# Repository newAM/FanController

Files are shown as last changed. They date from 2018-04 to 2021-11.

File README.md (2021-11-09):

## IR Fan Controller

### What is it?
This project is an Ethernet connected IR remote control for a the Seville classics ultra slimline tower fan, but it can be easily adapted to control other IR devices.  

### Why?
To connect my fan to Home Assistant so that it can turn on automatically when it gets hot, and turn off automatically when I leave home.

#### Why PoE?
Wireless home automation devices often make sense only when they are battery powered, if a power cable needs to be run it can carry data too.  Designing a low power wireless device is far more complicated than designing a wired device and running an Ethernet cable.

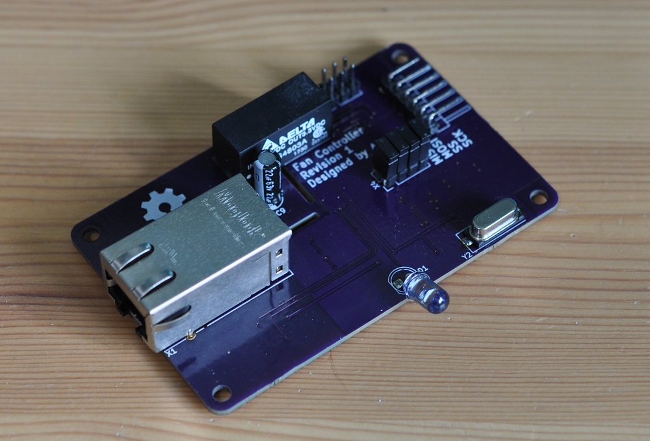
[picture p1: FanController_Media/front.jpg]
front


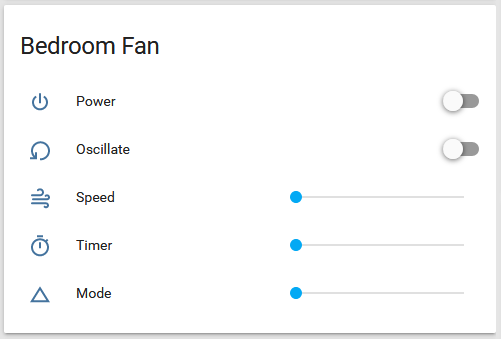
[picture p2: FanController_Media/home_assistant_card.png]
home_assistant_card


## Overview
Home Assistant → MQTT Broker → W5100 (Ethernet) → ATMega328P (MCU) → IR LED

The controller takes the states of the power, oscillation, mode, timer, and speed from Home Assistant.  These values are used to build the IR code then transmit it through the IR LED.

## Project Contents
* FanController_ArduinoCode - firmware for the ATMega328P
* FanController_Guide - reverse engineering guide for IR codes
* FanController_HomeAssistant - example Home Assistant configuration
* FanController_KiCAD - schematic and PCB
* FanController_Media - photos

## Software Used
* [KiCad](http://kicad.org/)
* [Arduino IDE](https://www.arduino.cc/en/Main/Software)
* [OpenSCAD](http://www.openscad.org/)
* [Libre Office](https://www.libreoffice.org/)
* [Home Assistant](https://www.home-assistant.io/)

### Arduino Libraries used
* [Arduino MQTT Client](https://github.com/knolleary/pubsubclient)

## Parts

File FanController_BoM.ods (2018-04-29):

Reference | Value | Tolerance | Rating | Package | Digikey P/N | Quantity
Integrated Circuits
U1 | ATMEGA328P-AU |  |  | 32-TQFP | ATMEGA328P-AU-ND | 1
U2 | NCP1090 |  |  | 8-SOIC | NCP1090DGOS-ND | 1
U3 | PG02S4803A |  |  | 8-SIP | 941-1185-ND | 1
U4 | W5100 |  |  | 80-LQFP (10) | 1278-1002-ND | 1
Resistors | Ohms |  | Watts
R1-R4 | 49.9 | 1% | 0.25 | 0805 | RNCP0805FTD49R9CT-ND | 4
R5 | 150 | 1% | 0.1 | 0603 | 311-150HRCT-ND | 1
R6 | 10 | 1% | 0.25 | 0805 | RNCP0805FTD10R0CT-ND | 1
R7, R13-R15 | 12k | 1% | 0.1 | 0603 | 311-12.0KHRCT-ND | 4
R8 | 24.9k | 1% | 0.1 | 0603 | 311-24.9KHRCT-ND | 1
R9 | 178k | 1% | 0.1 | 0603 | 311-178KHRCT-ND | 1
R10 | 4420 | 1% | 0.1 | 0603 | 311-4.42KHRCT-ND | 1
R11 | 300 | 1% | 0.1 | 0603 | 311-300HRCT-ND | 1
R12 | 1M | 5% | 0.1 | 0603 | 311-1.0MGRCT-ND | 1
Capacitors | Farads |  | Volts
C1-C6, C10-C12, C14, C16, C17 | 100n | 10% | 16 | 0603 | 1276-1005-1-ND | 10
C7 | 100n | 10% | 100 | 0805 | 1276-6840-1-ND | 1
C8 | 22u | 20% | 63 | 5mm | 493-12798-1-ND | 1
C9 | 10u | 10% | 10 | 0805 | 1276-6456-1-ND | 1
C13, C15 | 18p | 5% | 50 | 0603 | 1276-1089-1-ND | 2
Inductors | Henries |  | Amperes
L1 | 1u | 20% | 600m | 0603 | 445-3163-1-ND | 1
Oscillators | Hertz
Y1 | 8MHz |  |  |  | 490-1195-1-ND | 1
Y2 | 25M | 30ppm |  | HC49 | 535-10235-1-ND | 1
Connectors
X1 | 0813-1X1T-57-F |  |  |  | 507-1421-ND | 1
X2 | ICSP |  |  | 2*3 2.54mm | 952-1779-ND | 1
X3 | SPI Disconnect |  |  | 2*4 2.54mm | 952-2123-ND | 1
X4 | Serial Interface |  |  | 1*5 2.54mm RA | N/A | 1
Diodes
D1 | IR |  |  | 5mm |  | 1
D2, D3 | MDB6S |  |  | 4-MicroDIP | MDB6SFSCT-ND | 2
D4 | SMAJ58A |  |  | SMA | SMAJ58A-E3/61GICT-ND | 1
Transistors
Q1 | MMBT3904 |  |  | SOT-23-3 | MMBT3904LT1GOSCT-ND | 1
Other
Jumpers |  |  |  |  | S9000-ND | 4
PCB |  |  |  |  | N/A | 1

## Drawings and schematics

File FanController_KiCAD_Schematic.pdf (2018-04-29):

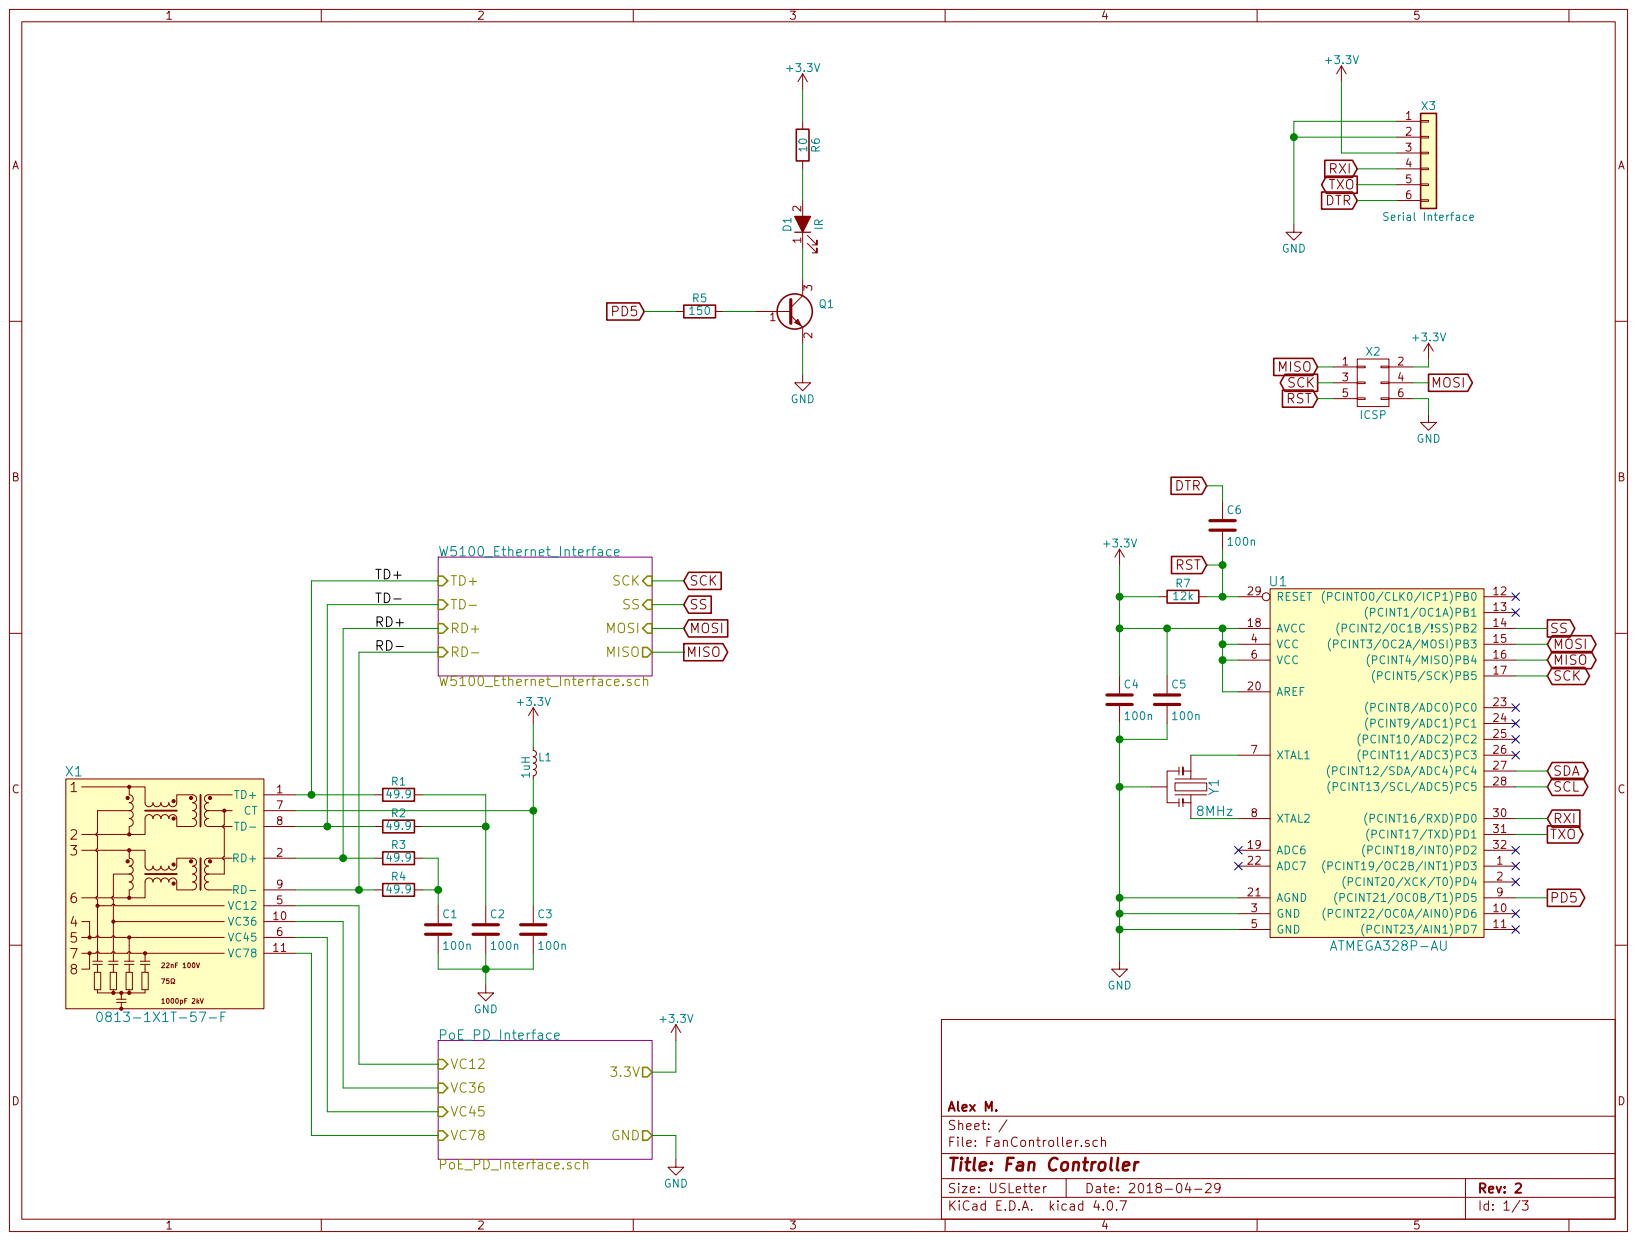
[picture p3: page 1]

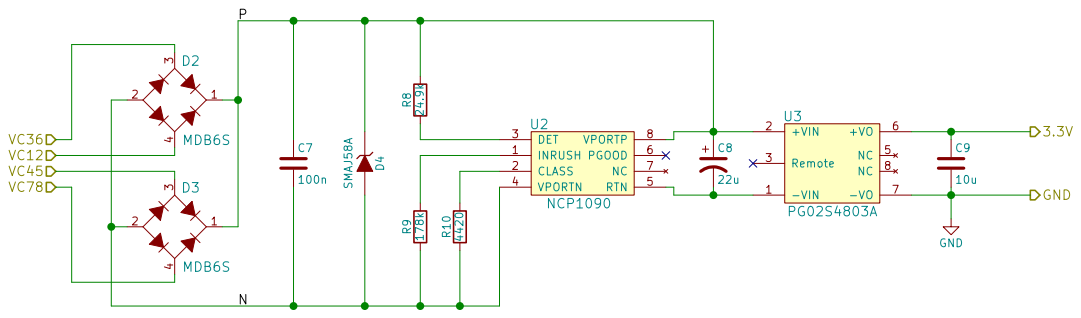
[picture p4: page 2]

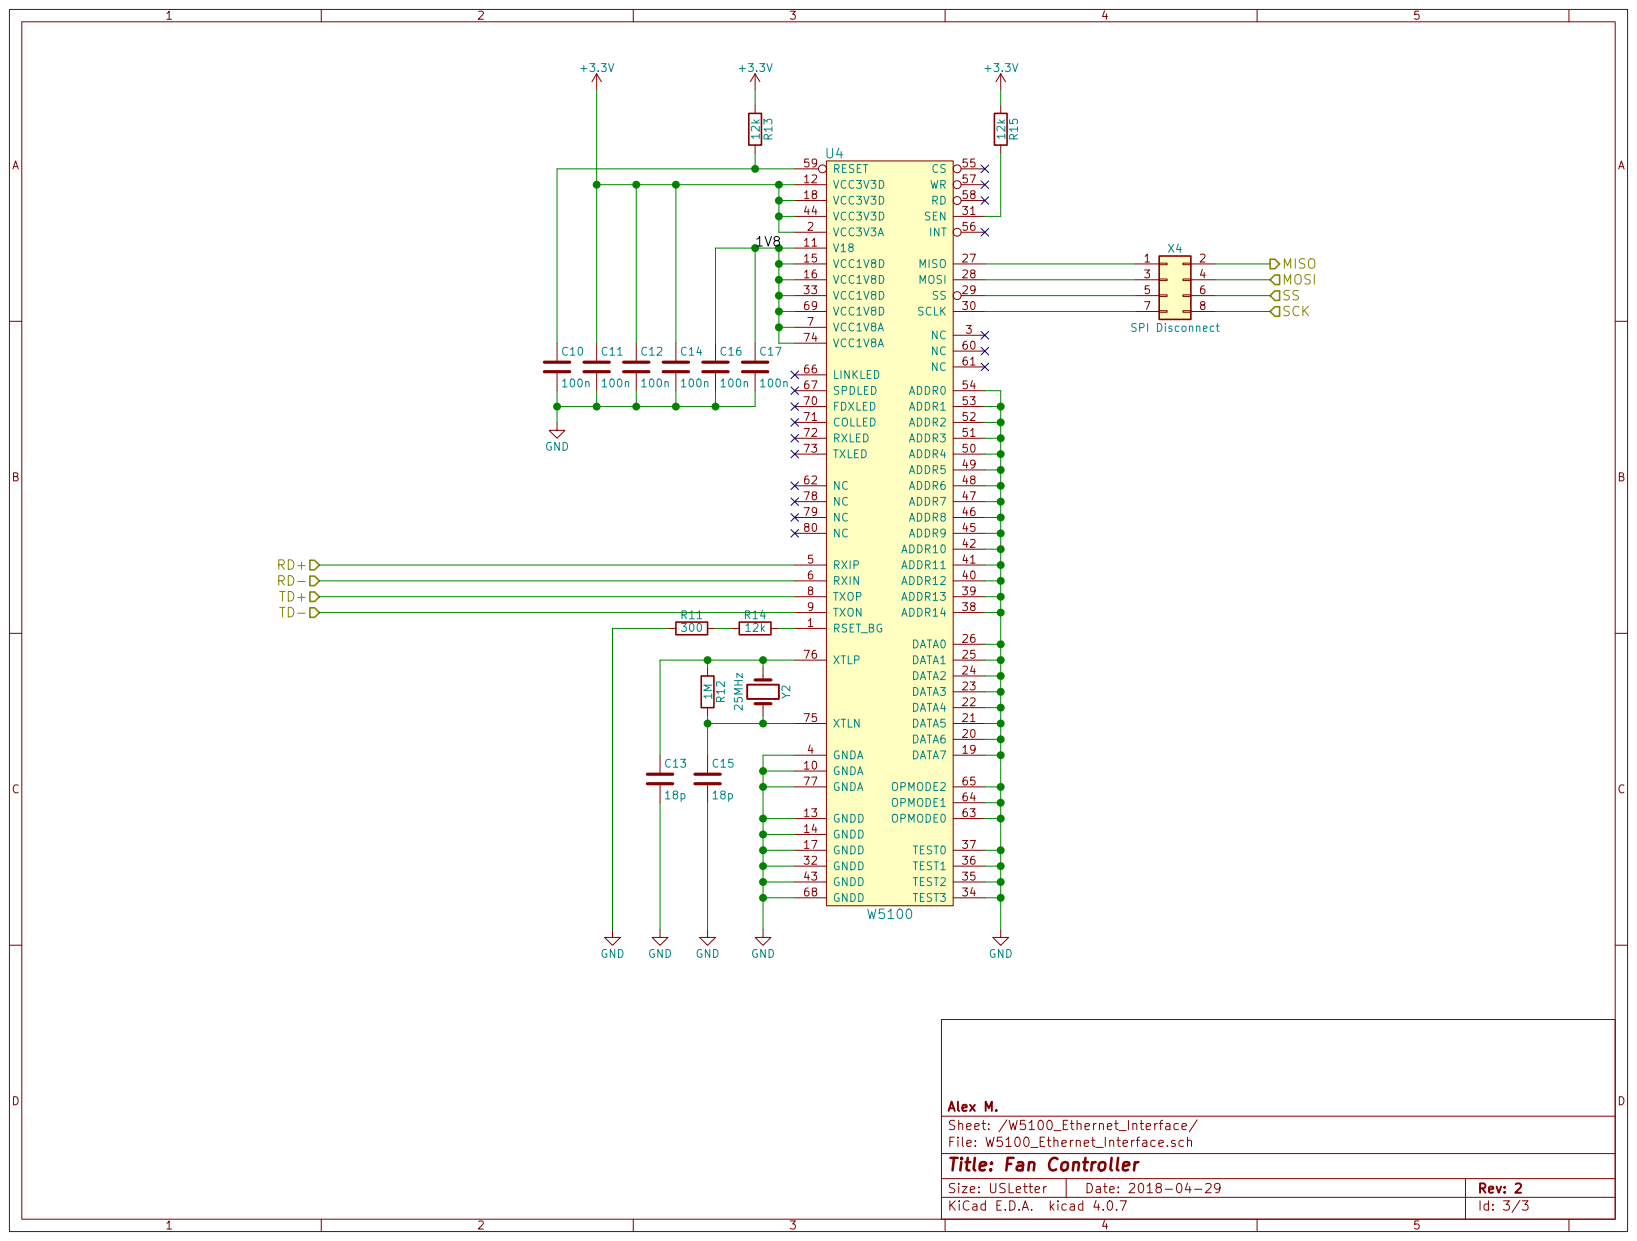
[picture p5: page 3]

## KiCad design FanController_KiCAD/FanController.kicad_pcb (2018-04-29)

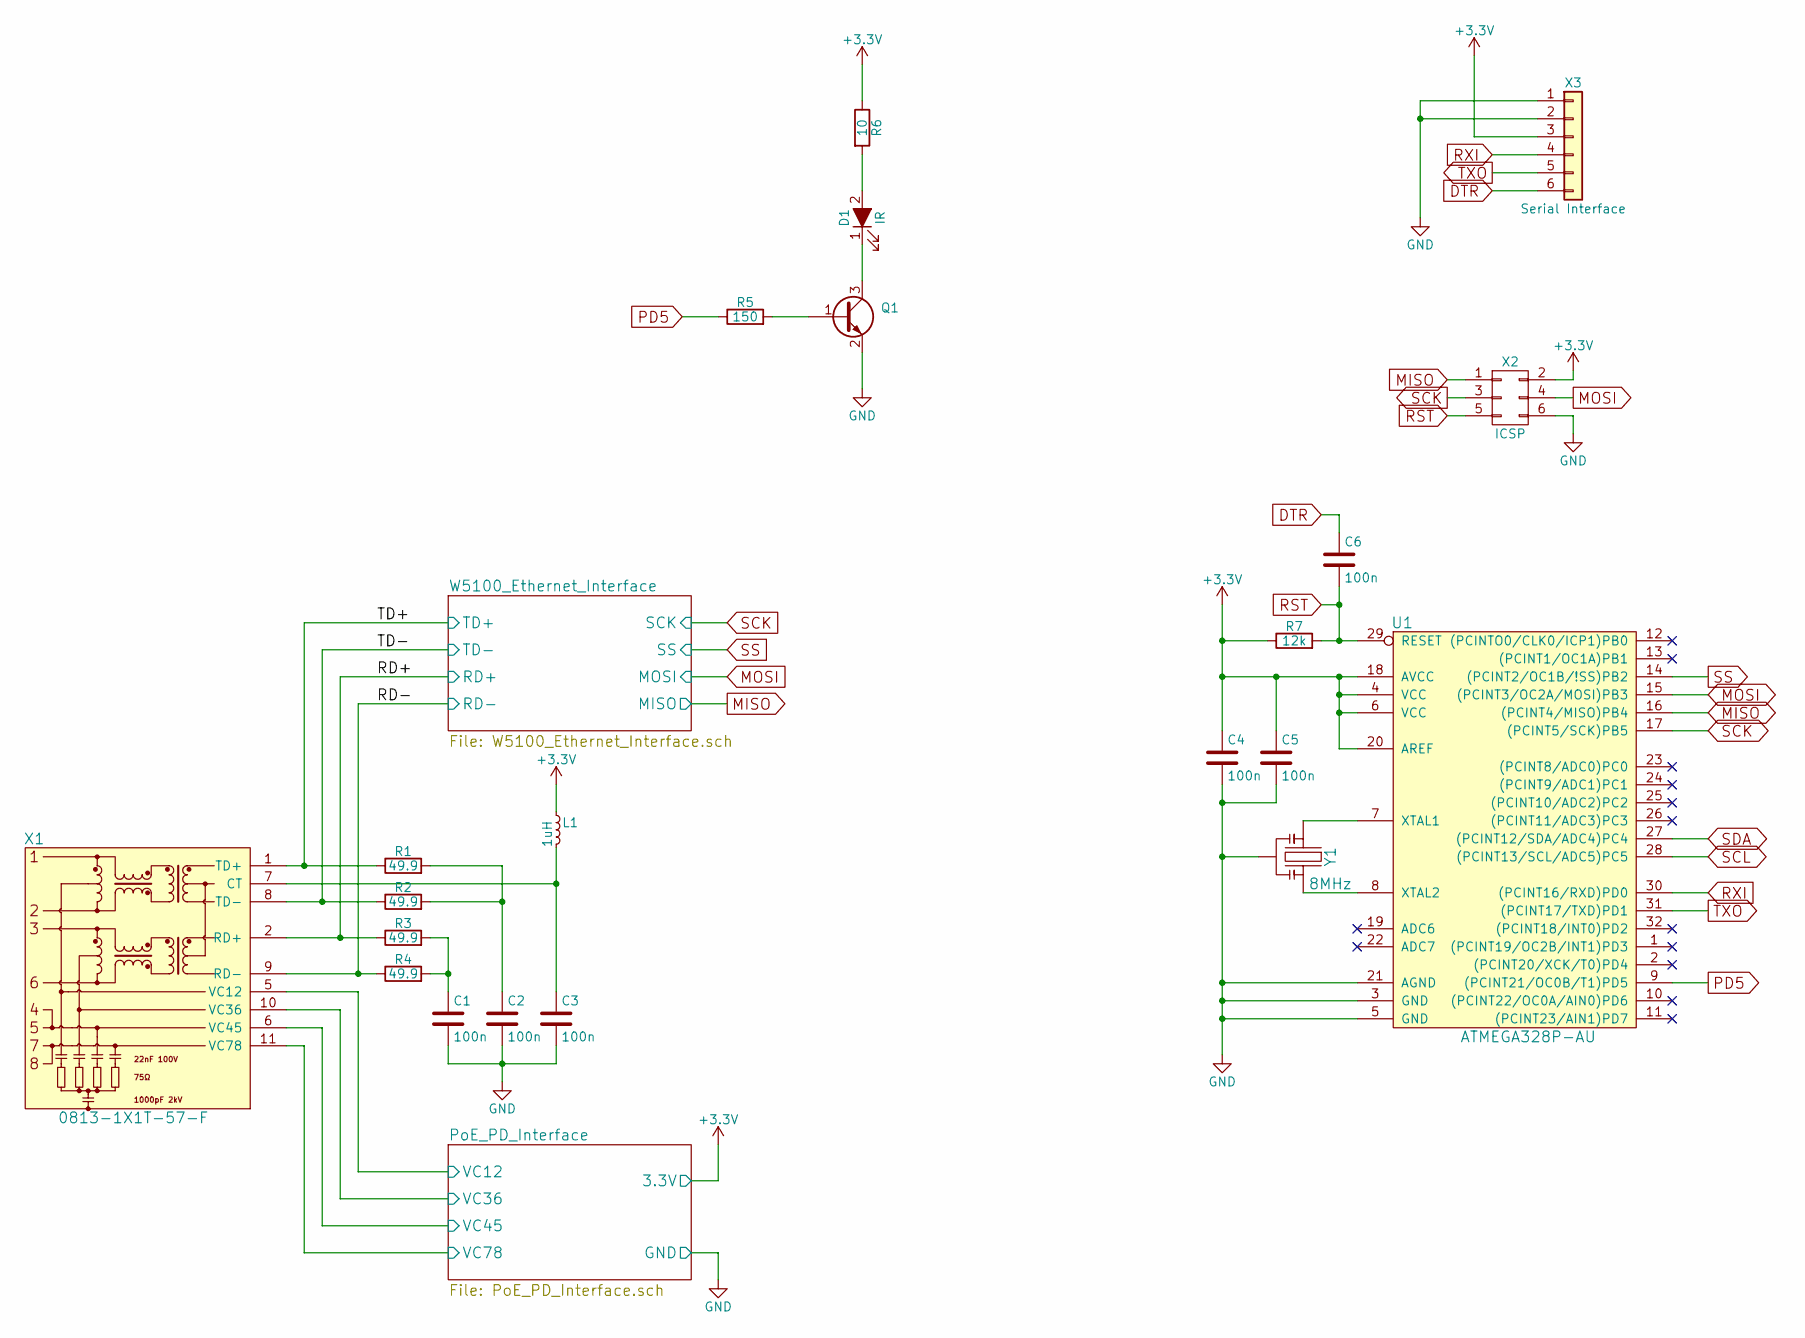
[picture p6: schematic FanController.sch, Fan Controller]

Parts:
C1, C2, C3, C4, C5, C6: 100n; C_0603; DigiKey Part Number 1276-1005-1-ND
D1: IR; LED_D5.0mm
L1: 1uH; C_0603; DigiKey Part Number 445-3163-1-ND
Q1: Q_NPN_BEC; SOT-23; DigiKey Part Number MMBT3904LT1GOSCT-ND
R1, R2, R3, R4: 49.9; R_0805; DigiKey Part Number RNCP0805FTD49R9CT-ND
R5: 150; R_0603; Tolerance 1%; DigiKey Part Number 311-150HRCT-ND
R6: 10; R_0805; DigiKey Part Number RNCP0805FTD10R0CT-ND
R7: 12k; R_0603; Tolerance 1%; DigiKey Part Number 311-12.0KHRCT-ND
U1: ATMEGA328P-AU; TQFP-32_7x7mm_Pitch0.8mm; DigiKey Part Number ATMEGA328P-AU-ND
X1: 0813-1X1T-57-F; 0813-1X1T-57-F_RJ45-Jack; DigiKey Part Number 507-1421-ND
X2: ICSP; Pin_Header_Straight_2x03_Pitch2.54mm
X3: Serial Interface; Pin_Header_Angled_1x06_Pitch2.54mm
Y1: 8MHz; CERALOCK_CSTCE_Resonator; DigiKey Part Number 490-1195-1-ND

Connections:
+3V3: C4.1, C5.1, L1.1, R6.1, R7.1, U1.4 (VCC), U1.6 (VCC), U1.18 (AVCC), U1.20 (AREF), X2.2, X3.3; also elsewhere on the board
/PoE_PD_Interface/VC12: X1.5 (VC12); also elsewhere on the board
/PoE_PD_Interface/VC36: X1.10 (VC36); also elsewhere on the board
/PoE_PD_Interface/VC45: X1.6 (VC45); also elsewhere on the board
/PoE_PD_Interface/VC78: X1.11 (VC78); also elsewhere on the board
/RD+: R3.1, X1.2 (RD+); also elsewhere on the board
/RD-: R4.1, X1.9 (RD-); also elsewhere on the board
/TD+: R1.1, X1.1 (TD+); also elsewhere on the board
/TD-: R2.1, X1.8 (TD-); also elsewhere on the board
DTR: C6.1, X3.6
GND: C1.2, C2.2, C3.2, C4.2, C5.2, Q1.2 (E), U1.3 (GND), U1.5 (GND), U1.21 (AGND), X2.6, X3.1, X3.2, Y1.2; also elsewhere on the board
MISO: U1.16 ((PCINT4/MISO)PB4), X2.1; also elsewhere on the board
MOSI: U1.15 ((PCINT3/OC2A/MOSI)PB3), X2.4; also elsewhere on the board
unnamed: C1.1, R3.2, R4.2
unnamed: C2.1, R1.2, R2.2
unnamed: C3.1, L1.2, X1.7 (CT)
unnamed: D1.1 (K), Q1.3 (C)
unnamed: D1.2 (A), R6.2
unnamed: Q1.1 (B), R5.2
unnamed: U1.7 (XTAL1), Y1.1
unnamed: U1.8 (XTAL2), Y1.3
PD5: R5.1, U1.9 ((PCINT21/OC0B/T1)PD5)
RST: C6.2, R7.2, U1.29 (RESET), X2.5
RXI: U1.30 ((PCINT16/RXD)PD0), X3.4
SCK: U1.17 ((PCINT5/SCK)PB5), X2.3; also elsewhere on the board
SS: U1.14 ((PCINT2/OC1B/!SS)PB2); also elsewhere on the board
TXO: U1.31 ((PCINT17/TXD)PD1), X3.5

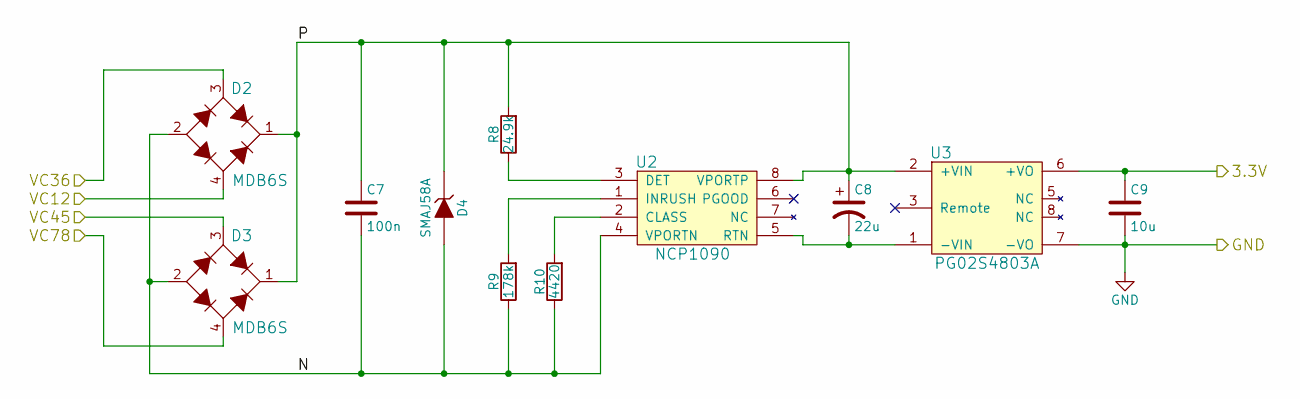
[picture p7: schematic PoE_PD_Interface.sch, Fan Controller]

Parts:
C7: 100n; C_0805; DigiKey Part Number 1276-6840-1-ND
C8: 22u; CP_Radial_D5.0mm_P2.00mm; DigiKey Part Number 493-12798-1-ND
C9: 10u; C_0805; DigiKey Part Number 1276-6456-1-ND
D2, D3: MDB6S; Micro-DIP-4; DigiKey Part Number MDB6SFSCT-ND
D4: SMAJ58A; D_SMA; DigiKey Part Number SMAJ58A-E3/61GICT-ND
R8: 24.9k; R_0603; DigiKey Part Number 311-24.9KHRCT-ND
R9: 178k; R_0603; DigiKey Part Number 311-178KHRCT-ND
R10: 4420; R_0603; DigiKey Part Number 311-4.42KHRCT-ND
U2: NCP1090; SOIC-8_3.9x4.9mm_Pitch1.27mm; DigiKey Part Number NCP1090DGOS-ND
U3: PG02S4803A; PG02S; DigiKey Part Number 941-1185-ND

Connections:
+3V3: C9.1, U3.6 (+VO); also elsewhere on the board
/PoE_PD_Interface/N: C7.2, D2.2 (-), D3.2 (-), D4.2 (A), R9.1, R10.1, U2.4 (VPORTN)
/PoE_PD_Interface/P: C7.1, C8.1, D2.1 (+), D3.1 (+), D4.1 (K), R8.2, U2.8 (VPORTP), U3.2 (+VIN)
/PoE_PD_Interface/VC12: D2.4 (AC2); also elsewhere on the board
/PoE_PD_Interface/VC36: D2.3 (AC1); also elsewhere on the board
/PoE_PD_Interface/VC45: D3.3 (AC1); also elsewhere on the board
/PoE_PD_Interface/VC78: D3.4 (AC2); also elsewhere on the board
GND: C9.2, U3.7 (-VO); also elsewhere on the board
unnamed: C8.2, U2.5 (RTN), U3.1 (-VIN)
unnamed: R8.1, U2.3 (DET)
unnamed: R9.2, U2.1 (INRUSH)
unnamed: R10.2, U2.2 (CLASS)

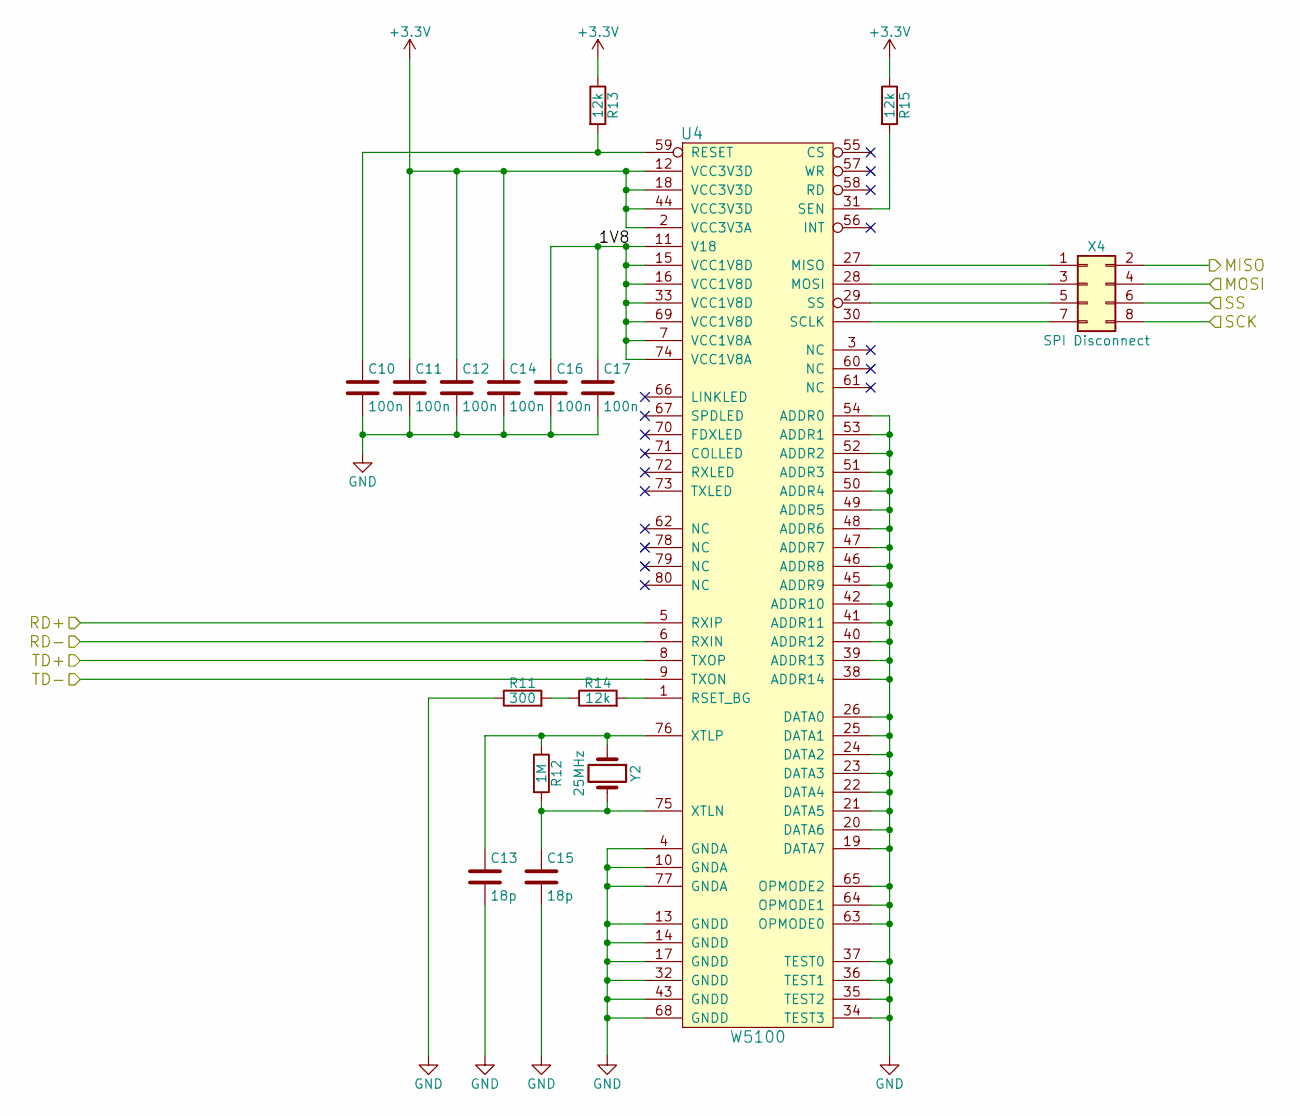
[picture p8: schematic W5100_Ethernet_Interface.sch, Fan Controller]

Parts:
C10, C11, C12, C14, C16, C17: 100n; C_0603; DigiKey Part Number 1276-1005-1-ND
C13, C15: 18p; C_0603; DigiKey Part Number 1276-1089-1-ND
R11: 300; R_0603; Tolerance 1%; DigiKey Part Number 311-300HRCT-ND
R12: 1M; R_0603; Tolerance 1%; DigiKey Part Number 311-1.00MHRCT-ND
R13, R14, R15: 12k; R_0603; Tolerance 1%; DigiKey Part Number 311-12.0KHRCT-ND
U4: W5100; LQFP-80_10x10mm_Pitch0.4mm; DigiKey Part Number 1278-1002-ND
X4: SPI Disconnect; Pin_Header_Straight_2x04_Pitch2.54mm
Y2: 25MHz; Crystal_SMD_HC49-SD; DigiKey Part Number 535-10235-1-ND

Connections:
+3V3: C11.1, C12.1, C14.1, R13.1, R15.1, U4.2 (VCC3V3A), U4.12 (VCC3V3D), U4.18 (VCC3V3D), U4.44 (VCC3V3D); also elsewhere on the board
/RD+: U4.5 (RXIP); also elsewhere on the board
/RD-: U4.6 (RXIN); also elsewhere on the board
/TD+: U4.8 (TXOP); also elsewhere on the board
/TD-: U4.9 (TXON); also elsewhere on the board
/W5100_Ethernet_Interface/1V8: C16.1, C17.1, U4.7 (VCC1V8A), U4.11 (V18), U4.15 (VCC1V8D), U4.16 (VCC1V8D), U4.33 (VCC1V8D), U4.69 (VCC1V8D), U4.74 (VCC1V8A)
GND: C10.2, C11.2, C12.2, C13.2, C14.2, C15.2, C16.2, C17.2, R11.1, U4.4 (GNDA), U4.10 (GNDA), U4.13 (GNDD), U4.14 (GNDD), U4.17 (GNDD), U4.19 (DATA7), U4.20 (DATA6), U4.21 (DATA5), U4.22 (DATA4), U4.23 (DATA3), U4.24 (DATA2), U4.25 (DATA1), U4.26 (DATA0), U4.32 (GNDD), U4.34 (TEST3), U4.35 (TEST2), U4.36 (TEST1), U4.37 (TEST0), U4.38 (ADDR14), U4.39 (ADDR13), U4.40 (ADDR12), U4.41 (ADDR11), U4.42 (ADDR10), U4.43 (GNDD), U4.45 (ADDR9), U4.46 (ADDR8), U4.47 (ADDR7), U4.48 (ADDR6), U4.49 (ADDR5), U4.50 (ADDR4), U4.51 (ADDR3), U4.52 (ADDR2), U4.53 (ADDR1), U4.54 (ADDR0), U4.63 (OPMODE0), U4.64 (OPMODE1), U4.65 (OPMODE2), U4.68 (GNDD), U4.77 (GNDA); also elsewhere on the board
MISO: X4.2; also elsewhere on the board
MOSI: X4.4; also elsewhere on the board
unnamed: C10.1, R13.2, U4.59 (RESET)
unnamed: C13.1, R12.1, U4.76 (XTLP), Y2.1
unnamed: C15.1, R12.2, U4.75 (XTLN), Y2.2
unnamed: R11.2, R14.1
unnamed: R14.2, U4.1 (RSET_BG)
unnamed: R15.2, U4.31 (SEN)
unnamed: U4.27 (MISO), X4.1
unnamed: U4.28 (MOSI), X4.3
unnamed: U4.29 (SS), X4.5
unnamed: U4.30 (SCLK), X4.7
SCK: X4.8; also elsewhere on the board
SS: X4.6; also elsewhere on the board

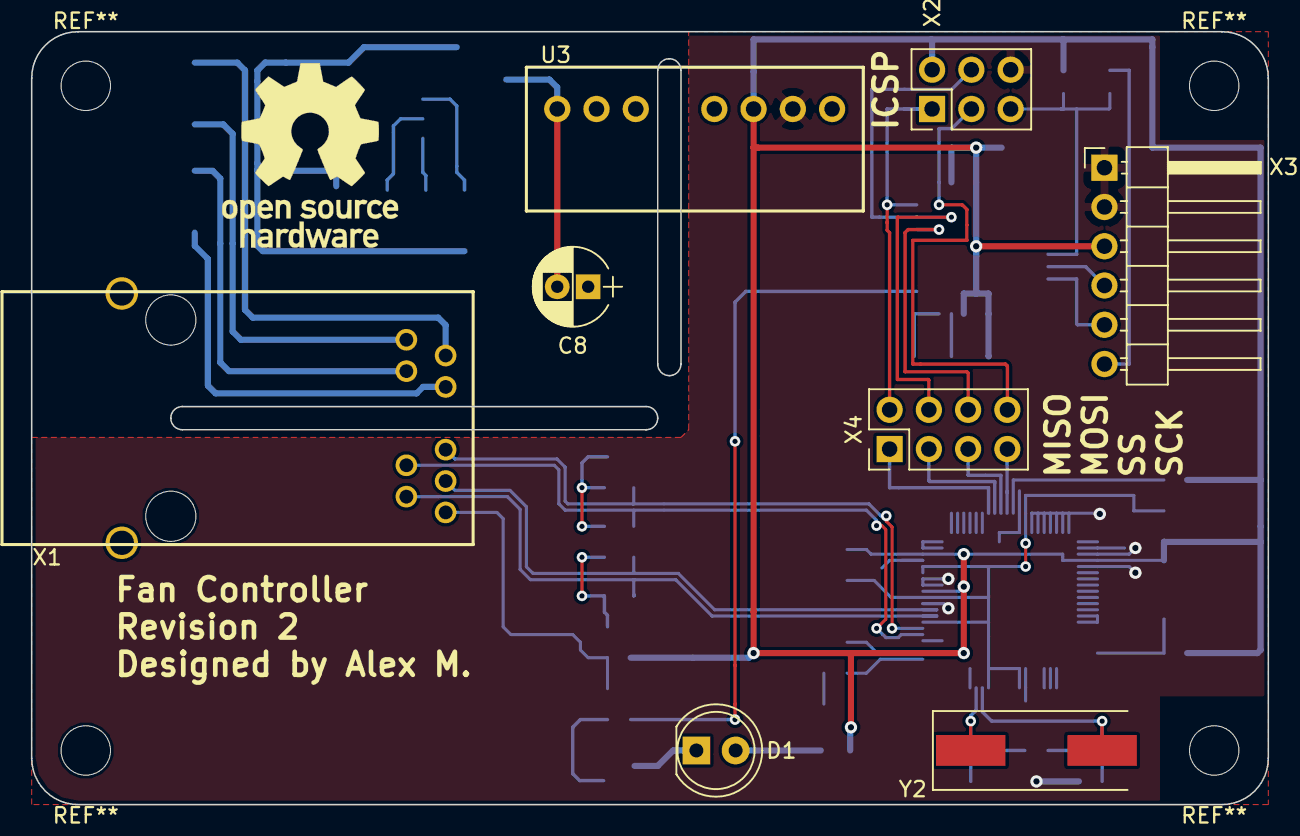
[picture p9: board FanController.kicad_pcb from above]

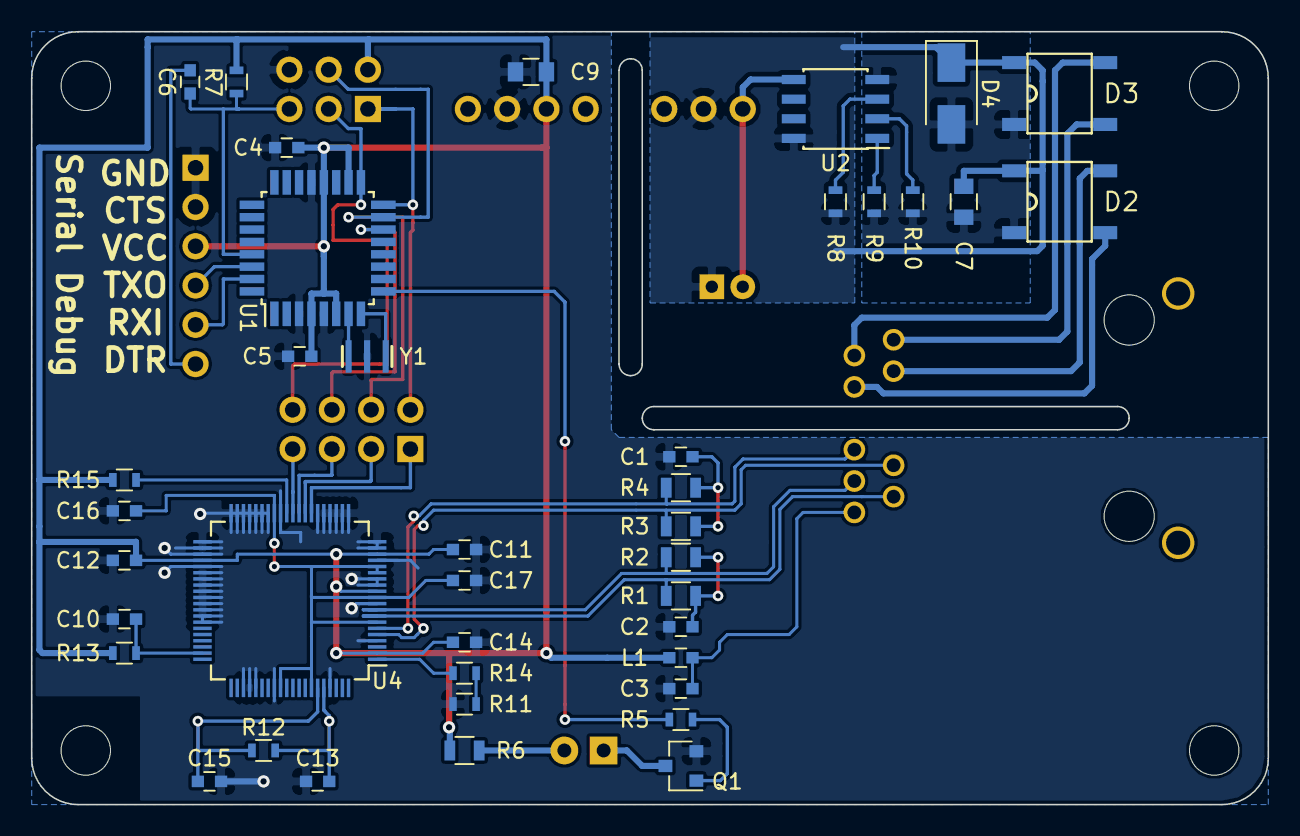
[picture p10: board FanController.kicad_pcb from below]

Board: 2 copper layers, 80.0 x 50.0 mm, 48 parts (40 on the bottom side), 44 nets.

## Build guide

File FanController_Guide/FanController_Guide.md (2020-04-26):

## Contents
- [Introduction](#introduction)
- [Background](#background)
    - [IR Data Formats](#ir-data-formats)
    - [Types of IR Remotes](#types-of-ir-remotes)
        - [Types of IR Remotes](#single-command-remotes)
        - [All at Once Remotes](#all-at-once-remotes)
- [Reading IR Commands](#reading-ir-commands)
- [Determining the Protocol](#determining-the-protocol)

## Introduction

This is not a full guide to reverse engineering IR remote controls.  This guide outlines the process I went through to create this controller, and provides some guidance on adapting it for your application.

## Background

This guide will not go into the very basics behind IR communication, check out [this guide](http://www.learn.sparkfun.com/tutorials/ir-communication) by SparkFun to get the basics of IR communication.

### IR Data Formats

There's a few different types of data formats for IR remote controls, and a few common carrier frequencies. The most common carrier frequency for IR remotes is 38kHz, it is usually a good idea to start there.

[This document](http://www.vishay.com/docs/80071/dataform.pdf) by VISHAY covers the data formats and carrier frequencies that you are likely to come across when reverse engineering an IR remote control.

### Types of IR Remotes

There are two common types of IR remotes, single command remotes and all at once remotes

#### Single Command Remotes

Most remotes are single command remotes that send an 8-bit value to send up to 256 unique commands.  These remotes typically do not store the device state on the remote (e.g. A TV remote does not store the volume level of the TV), they simply indicate to the device to change its current state (e.g. increasing the volume on the TV). 

#### All at Once Remotes

All at once remotes store the device state on the remote, and send the desired device state to be set.  For example, an all at once TV remote would store the volume level and instead of telling the TV to increase or decrease the volume it would send an absolute number (e.g. set the volume to 50%) to the TV.

The codes are significantly longer because they send all of states all at once, in one command.  For the fan I am using this includes the mode, the timer, the speed, the oscillation state, and the power.

All at once remotes are most commonly used for air conditioners, and fire places, but it turns out that my fan uses this type of remote too.  The giveaway was that it had a LCD that showed the fan state; this was confirmed by setting a timer with the buttons physically located on the fan, and then setting a timer using the remote.  Whatever state was stored on the fan would be reset with the value stored on the remote.

## Reading IR Commands

Starting with a Raspberry Pi 3 wire up a 38kHz receiver (e.g. the [VISHAY TSSP58038](http://www.vishay.com/docs/82479/tssp58038.pdf)) with pin 1 connected to GPIO 23 (pin 16) on the pi, pin 2 connected to ground, and pin 3 connected to 3.3V.  I used a [Pi cobbler breakout](http://www.adafruit.com/product/2029) to make the wiring easier.

Now that the pi is wired up it's time for some code.  I wrote a small python script below that checks for a state change on the IR receiver then prints the state, and the duration of the state in μs.

```python
#!/usr/bin/env python

import time
import RPi.GPIO as gpio  # noqa: N813

# GPIO 23 is pin 16 on the Raspberry Pi 3
ir_receiver = 16

# set GPIO numbering system to board
gpio.setmode(gpio.BOARD)

# set ir_receiver pin to input
gpio.setup(ir_receiver, gpio.IN)

# initialize variables
prev_state = 1
start_time = time.time()

while True:

    # read GPIO
    state = gpio.input(ir_receiver)

    # check for state transition
    if state != prev_state:

        # time since last transition in us
        end_time = time.time()
        total_time = (end_time - start_time) * 1000000

        # print results
        print("%d %d" % (prev_state, total_time))

        # store previous values
        prev_state = state
        start_time = end_time
```

To use this on your pi you need to download the script, add executable permissions, and run it.

```
wget https://raw.githubusercontent.com/newAM/FanController/master/FanController_Guide/irReceive.py
wget https://raw.githubusercontent.com/newAM/FanController/master/FanController_Guide/irReceiveNEC.py
chmod +x irReceive.py
./irReceive.py
```

When the power button on my fan remote is pressed I get an output similar to this, but much longer.  The first 1 is insignificant because that is the time from running the script to pressing the button on my remote. '1' represents the default state of the IR receiver when nothing is received, and '0' represents the active state when the receiver is being send a 38kHz square wave from the remote.

```
1 2634145
0 9390
1 4862
0 537
1 590
0 540
1 588
0 542
1 587
0 541
1 1682
0 539
1 591
0 540
1 601
0 538
1 590
0 540
1 1702
0 539
1 589
0 542
```

Referencing [VISHAY's IR data formats data sheet](http://www.vishay.com/docs/80071/dataform.pdf) from before it is clear that the fan remote uses the NEC code because the leader code consists of a 9000μs burst followed by a 4500μs pause.

## Determining the Protocol

Now that the data format is determined the previous script can be improved to print the formatted code from the remote.

The for each bit NEC code first sends a burst portion followed by a gap.  The burst is always a constant 578.6μs, and the length of the following gap represents the bit.  A '0' is represented with a 1125μs pulse distance, and a '1' with a 2250μs pulse distance.  Using this I can improve the program to simply print the bits in each code.

```python
#!/usr/bin/env python

import time
import sys
import RPi.GPIO as gpio  # noqa: N813

# GPIO 23 is pin 16 on the Raspberry Pi 3
ir_receiver = 16

# set GPIO numbering system to board
gpio.setmode(gpio.BOARD)

# set ir_receiver pin to input
gpio.setup(ir_receiver, gpio.IN)

# initialize variables
prev_state = 1
start_time = time.time()

# constants
leader_time = 4000
high_time = 1000

while True:

    # read GPIO
    state = gpio.input(ir_receiver)

    # check for state transition
    if state != prev_state:

        # time since last transition in us
        end_time = time.time()
        total_time = (end_time - start_time) * 1000000

        # compare high states
        if prev_state == 1:
            # check if leader code or determine bit
            if total_time > leader_time:
                sys.stdout.write("\n")
            elif total_time > high_time:
                sys.stdout.write("1")
            else:
                sys.stdout.write("0")

        sys.stdout.flush()

        # store previous values
        prev_state = state
        start_time = end_time
```

The program now prints the raw codes in binary.  I tested every state on the remote to determine what buttons controlled which bits, and compiled them below, showing which bits changed.

```
power
0001000000100000001100000100001101010000000000000110000001110011 off
0001000100100000001100000100001101010000000000000110000001110010 on
-------*------------------------------------------------------**

speed
0001000100100000001100000100001101010000000000000110000001110010 eco
0001000100100000001100000100000001010000000000000110000001110001 low
0001000100100000001100000100000101010000000000000110000001110000 med
0001000100100000001100000100001001010000000000000110000001110011 high
------------------------------**------------------------------**

sleep timer
0001000100100000001100000100001101010000000000000110000001110010 0.0h
0001000100100001001100000100001101010000000000000110000001110011 0.5h
0001000100100010001100000100001101010000000000000110000001110000 1.0h
0001000100100011001100000100001101010000000000000110000001110001 1.5h
0001000100100100001100000100001101010000000000000110000001110110 2.0h
0001000100100101001100000100001101010000000000000110000001110111 2.5h
0001000100100110001100000100001101010000000000000110000001110100 3.0h
0001000100100111001100000100001101010000000000000110000001110101 3.5h
0001000100101000001100000100001101010000000000000110000001111010 4.0h
0001000100101001001100000100001101010000000000000110000001111011 4.5h
0001000100101010001100000100001101010000000000000110000001111000 5.0h
0001000100101011001100000100001101010000000000000110000001111001 5.5h
0001000100101100001100000100001101010000000000000110000001111110 6.0h
0001000100101101001100000100001101010000000000000110000001111111 6.5h
0001000100101110001100000100001101010000000000000110000001111100 7.0h
0001000100101111001100000100001101010000000000000110000001111101 7.5h
------------****--------------------------------------------****

oscillation
0001000100100000001100000100001101010000000000000110000001110010 off
0001000100100000001100010100001101010000000000000110000001110011 on
-----------------------*---------------------------------------*

mode
0001000100100000001100000100001101010000000000000110000001110010 reg
0001000100100000001100000100001101010001000000000110000001110011 wind
0001000100100000001100000100001101010010000000000110000001110000 sleep
--------------------------------------**----------------------**
```

In total 14 bits change to control every state on the fan.  1 bit each for power and oscillation, 2 bits each for the mode and speed, and 4 bits for the timer.  At the end of each IR code there are also 4 bits changing each time.  This is a simple CRC code which is just the XOR sum of the power, oscillation, mode, speed, and timer bits.

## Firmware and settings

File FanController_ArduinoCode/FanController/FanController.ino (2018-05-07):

// communications
#include <SPI.h>            // for Ethernet.h
#include <Ethernet.h>       // W5100
#include <PubSubClient.h>   // MQTT

// utility
#include <stdio.h>          // sscanf()
#include <util/delay.h>     // _delay_us

// project files for IR transmission
#include "SendIR.h"

// macro constants
#define TIMEOUT   5000 // connection failure timeout in ms
#define SER_BAUD  9600 // serial port baud rate
#define MQTT_PORT 1883 // MQTT broker port
#define MQTT_CLIENT_ID "bedFan" // MQTT client ID

// MQTT topics
#define TOPIC_BASE  "/home/bedroom/fan"
#define TOPIC_SPEED TOPIC_BASE "/speed"
#define TOPIC_MODE  TOPIC_BASE "/mode"
#define TOPIC_TIMER TOPIC_BASE "/timer"
#define TOPIC_POWER TOPIC_BASE "/power"
#define TOPIC_OSC   TOPIC_BASE "/oscillate"

// client objects
EthernetClient ethClient;
PubSubClient mqttClient(ethClient);

// reconnects to the MQTT broker
void reconnect()
{
    // loop while disconnected
    while (!mqttClient.connected())
    {
        // attempt to connect
        Serial.println("Attempting to establish connection to MQTT broker...");
        if (mqttClient.connect(MQTT_CLIENT_ID)) 
        {
            // print connection messaged for debug
            Serial.println("Connection established");
            mqttClient.publish(TOPIC_BASE, "connected");

            // subscribe to each control topic
            mqttClient.subscribe(TOPIC_SPEED);
            mqttClient.subscribe(TOPIC_MODE);
            mqttClient.subscribe(TOPIC_TIMER);
            mqttClient.subscribe(TOPIC_POWER);
            mqttClient.subscribe(TOPIC_OSC);
        }
        else
        {
            Serial.print("Failed to connect: ");

            // print client state
            switch (mqttClient.state())
            {
                case MQTT_CONNECTION_TIMEOUT:
                    Serial.println("MQTT_CONNECTION_TIMEOUT");
                    break;
                case MQTT_CONNECTION_LOST:
                    Serial.println("MQTT_CONNECTION_LOST");
                    break;
                case MQTT_CONNECT_FAILED:
                    Serial.println("MQTT_CONNECT_FAILED");
                    break;
                case MQTT_DISCONNECTED:
                    Serial.println("MQTT_DISCONNECTED");
                    break;           
                case MQTT_CONNECTED:
                    Serial.println("MQTT_CONNECTED");
                    break;
                case MQTT_CONNECT_BAD_PROTOCOL:
                    Serial.println("MQTT_CONNECT_BAD_PROTOCOL");
                    break;
                case MQTT_CONNECT_BAD_CLIENT_ID:
                    Serial.println("MQTT_CONNECT_BAD_CLIENT_ID");
                    break;
                case MQTT_CONNECT_UNAVAILABLE:
                    Serial.println("MQTT_CONNECT_UNAVAILABLE");
                    break;
                case MQTT_CONNECT_BAD_CREDENTIALS:
                    Serial.println("MQTT_CONNECT_BAD_CREDENTIALS");
                    break;
                case MQTT_CONNECT_UNAUTHORIZED:
                    Serial.println("MQTT_CONNECT_UNAUTHORIZED");
                    break;
                default:
                    Serial.println("MQTT_STATE_UNKNOWN");
                    break;
            }

            // delay before next attempt
            delay(TIMEOUT);
        } 
    }
}

// callback function for handling new messages on subscribed topics
void callback(char* topic, byte* payload, unsigned int length)
{
    // copy payload
    byte* p = (byte*) malloc(length);
    memcpy(p, payload, length);
    payload = "";

    // fan control variables
    static uint8_t speed = 0;
    static uint8_t mode  = 0;
    static uint8_t timer = 0;
    static uint8_t power = 0;
    static uint8_t osc   = 0;

    // set the variables
    if (strcmp(topic, TOPIC_SPEED) == 0)
    {
        speed = atoi(p);
    }
    else if (strcmp(topic, TOPIC_MODE) == 0)
    {
        mode = atoi(p);
    }
    else if (strcmp(topic, TOPIC_TIMER) == 0)
    {
        timer = atoi(p);
    }
    else if (strcmp(topic, TOPIC_POWER) == 0)
    {
        power = atoi(p);
    }
    else if (strcmp(topic, TOPIC_OSC) == 0)
    {
        osc = atoi(p);
    }

    // free memory
    free(p);

    // send IR command
    sendCommand(speed, mode, timer, power, osc);
}

void setup()
{
    // network settings
    uint8_t myMAC[] = {0x88, 0xAA, 0xBB, 0xCC, 0xDE, 0x04}; // device MAC
    IPAddress mqttBroker(10, 0, 0, 4); // MQTT broker IP

    // open serial connection
    Serial.begin(SER_BAUD);

    // print status
    Serial.println("Serial connected!");
    Serial.println("Configuring Ethernet with DHCP...");
    
    // connect with DHCP
    while (!Ethernet.begin(myMAC))
    {
        Serial.println("Failed to configure Ethernet using DHCP");
        delay(TIMEOUT);
    }

    // print IP address
    Serial.println("Ethernet connected!");
    Serial.print("My IP: ");
    Serial.println(Ethernet.localIP());

    // configure MQTT broker
    mqttClient.setServer(mqttBroker, MQTT_PORT);

    // set callback function
    mqttClient.setCallback(callback);

    // set IR LED as output
    pinMode(LED_PIN, OUTPUT);
}

void loop()
{
    // connect if disconnected
    if (!mqttClient.connected())
    {
        reconnect();
    }

    // maintain connection
    mqttClient.loop();
}

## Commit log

2018-05-07 fixed static control variable memory
    [FanController.ino, SendIR.h]
2021-11-09 Update kicad URL
    https://forum.kicad.info/t/warning-avoid-all-links-to-kicad-pcb-org-use-kicad-org/31521
